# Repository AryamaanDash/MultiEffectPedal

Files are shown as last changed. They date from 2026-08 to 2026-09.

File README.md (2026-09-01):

# MultiEffectPedal

## Description

Multi-effect guitar pedal firmware and a custom KiCad PCB for the Daisy Seed.
The firmware runs distortion, stereo reverb, delay, and flanger effects at the
Daisy audio sample rate, with a footswitch for cycling through the effects.

## Firmware architecture

```text
src/main.cpp             Hardware composition and application entry point
src/AudioEngine.cpp      Real-time block processing and output limiting
src/EffectManager.cpp    Effect ownership-independent routing and mode changes
src/PedalControls.cpp    Foreground switch scanning and LED state
src/effects/             Individual DSP effect adapters
include/                 Public interfaces and shared audio types
```

Every effect implements the `EffectProcessor` interface:

```cpp
virtual void Init(float sample_rate) = 0;
virtual void SetParameters(const EffectParameters& parameters) = 0;
virtual StereoFrame Process(float input) = 0;
```

Effect parameters use normalized values from 0 to 1. Each adapter maps those
values to the range expected by its DaisySP processor. Mode changes are sent
from the foreground loop through an atomic request and applied by the audio
engine at the next block boundary.

The reverb and one-second delay buffers remain in external SDRAM. Effect
objects and the manager are statically allocated; audio processing performs no
dynamic allocation.

## Building

This project expects `libDaisy` and `DaisySP` to be available at the paths in
the `Makefile`.

```sh
make
```

To add an effect, implement `EffectProcessor`, register the instance with
`EffectManager`, and add its source file to `CPP_SOURCES` in the `Makefile`.

## Tools

- Daisy Seed and libDaisy
- DaisySP and DaisySP-LGPL
- KiCad PCB and schematic design

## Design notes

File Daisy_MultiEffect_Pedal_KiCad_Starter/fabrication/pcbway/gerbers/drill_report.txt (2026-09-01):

Drill report for Daisy_MultiEffect_Pedal.kicad_pcb
Created on 2026-08-16T17:45:17

Copper Layer Stackup:
    =============================================================
    L1 :  F.Cu                      front
    L2 :  B.Cu                      back

Drill file 'Daisy_MultiEffect_Pedal.drl' contains
    plated through holes:
    =============================================================
    T1  0.800mm  0.0315"  (36 holes))
    T2  0.900mm  0.0354"  (55 holes))
    T3  1.200mm  0.0472"  (6 holes))

    Total plated holes count 97

Not plated through holes are merged with plated holes
    unplated through holes:
    =============================================================

    Total unplated holes count 0

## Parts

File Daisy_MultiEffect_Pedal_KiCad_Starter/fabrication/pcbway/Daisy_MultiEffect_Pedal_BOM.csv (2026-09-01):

Refs | Value | Footprint | Qty | DNP
C1 | 10uF VREF bulk | Custom:TH_2Pin_7p62 | 1
C2 | 100nF VREF bypass | Custom:TH_2Pin_7p62 | 1
C3 | 100nF op-amp decouple | Custom:TH_2Pin_7p62 | 1
C4 | 1uF input coupling | Custom:TH_2Pin_7p62 | 1
C5 | 1uF into Daisy | Custom:TH_2Pin_7p62 | 1
C6 | 1uF from Daisy Out | Custom:TH_2Pin_7p62 | 1
C7 | 10uF final output coupling | Custom:TH_2Pin_7p62 | 1
J1 | Input TS jack: tip/sleeve | Custom:Jack_or_Switch_2Pin | 1
J2 | Output TS jack: tip/sleeve | Custom:Jack_or_Switch_2Pin | 1
R1 | 100k VREF top | Custom:TH_2Pin_7p62 | 1
R2 | 100k VREF bottom | Custom:TH_2Pin_7p62 | 1
R3 | 1M to VREF | Custom:TH_2Pin_7p62 | 1
R4 | 100R | Custom:TH_2Pin_7p62 | 1
R5 | 100k output bias | Custom:TH_2Pin_7p62 | 1
R6 | 100R output iso | Custom:TH_2Pin_7p62 | 1
R7 | 100k pulldown | Custom:TH_2Pin_7p62 | 1
RV1 | B10K wet/dry | Custom:Pot_3Pin_B10K_Wired | 1
RV2 | B10K amount | Custom:Pot_3Pin_B10K_Wired | 1
RV3 | B10K time/rate | Custom:Pot_3Pin_B10K_Wired | 1
RV4 | B10K feedback | Custom:Pot_3Pin_B10K_Wired | 1
RV5 | B10K output level | Custom:Pot_3Pin_B10K_Wired | 1
SW1 | Momentary mode switch | Custom:Jack_or_Switch_2Pin | 1
U1 | MCP6002 dual op-amp | Package_DIP:DIP-8_W7.62mm | 1
U2 | Daisy Seed minimal pinout | Custom:Daisy_Seed_2x20_Socket | 1

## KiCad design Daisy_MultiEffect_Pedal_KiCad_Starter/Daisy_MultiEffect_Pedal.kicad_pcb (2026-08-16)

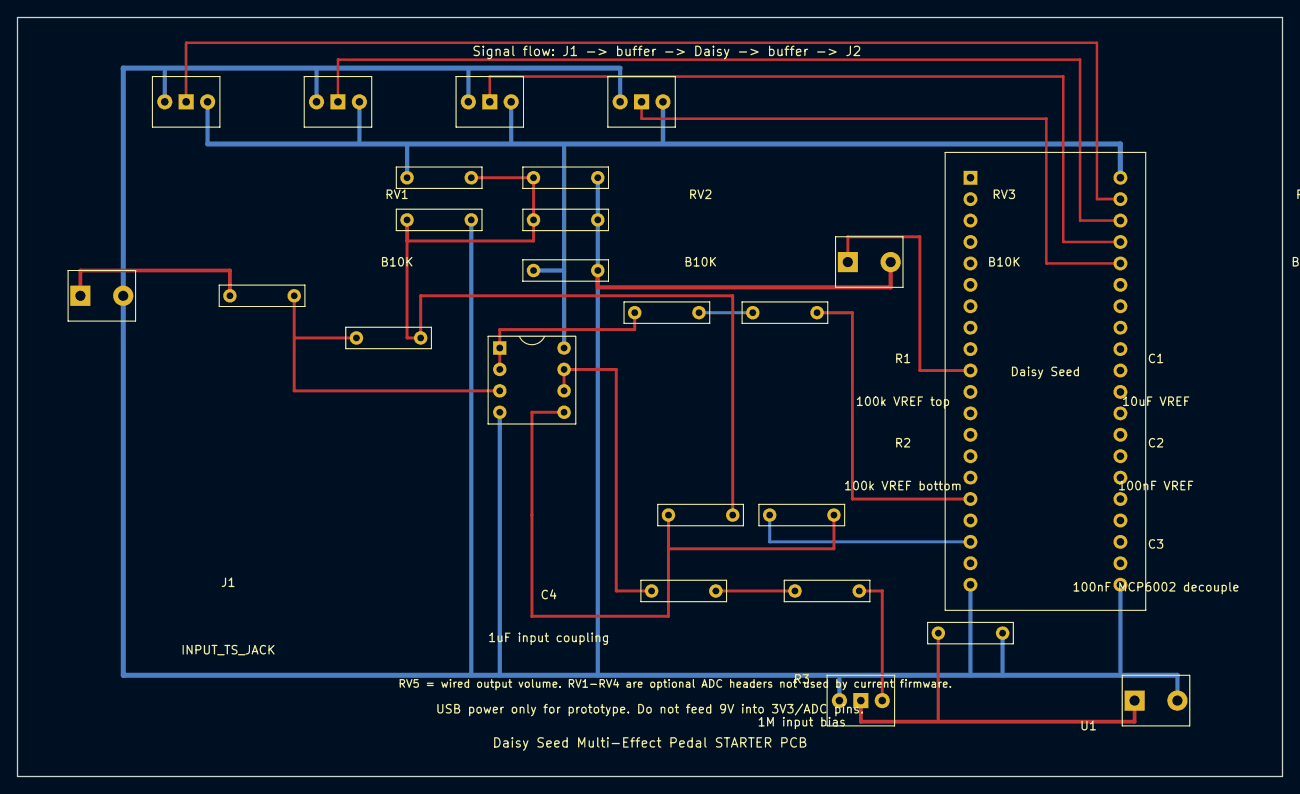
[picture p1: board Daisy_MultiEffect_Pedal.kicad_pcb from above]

Board: 2 copper layers, 150.0 x 90.0 mm, 24 parts (0 on the bottom side), 19 nets.

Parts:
C1: 10uF VREF; TH_2Pin_7p62
C2: 100nF VREF; TH_2Pin_7p62
C3: 100nF MCP6002 decouple; TH_2Pin_7p62
C4: 1uF input coupling; TH_2Pin_7p62
C5: 1uF to Daisy In; TH_2Pin_7p62
C6: 1uF from Daisy Out; TH_2Pin_7p62
C7: 10uF output coupling; TH_2Pin_7p62
J1: INPUT_TS_JACK; Jack_or_Switch_2Pin
J2: OUTPUT_TS_JACK; Jack_or_Switch_2Pin
R1: 100k VREF top; TH_2Pin_7p62
R2: 100k VREF bottom; TH_2Pin_7p62
R3: 1M input bias; TH_2Pin_7p62
R4: 100R; TH_2Pin_7p62
R5: 100k out bias; TH_2Pin_7p62
R6: 100R out iso; TH_2Pin_7p62
R7: 100k output pulldown; TH_2Pin_7p62
RV1, RV2, RV3, RV4: B10K; Pot_3Pin_B10K_Wired
RV5: B10K volume; Pot_3Pin_B10K_Wired
SW1: MOMENTARY_MODE_SWITCH; Jack_or_Switch_2Pin
U1: MCP6002-I/P; DIP-8_W7.62mm
U2: Daisy Seed socket / 2x20; Daisy_Seed_2x20_Socket

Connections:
+3V3A: C3.1, R1.1, RV1.3 (CW/3V3A), RV2.3 (CW/3V3A), RV3.3 (CW/3V3A), RV4.3 (CW/3V3A), U1.8, U2.21 (PIN21)
AUDIO_IN_L: C5.2, U2.16 (PIN16)
AUDIO_OUT_L: C6.1, U2.18 (PIN18)
BUF_IN_OUT: R4.1, U1.1, U1.2
BUF_TO_DAISY_C: C5.1, R4.2
D9_SWITCH: SW1.1 (TIP/SW1), U2.10 (PIN10)
GND: C1.2, C2.2, C3.2, J1.2 (SLEEVE/SW2), J2.2 (SLEEVE/SW2), R2.2, R7.2, RV1.1 (CCW/GND), RV2.1 (CCW/GND), RV3.1 (CCW/GND), RV4.1 (CCW/GND), RV5.1 (CCW/GND), SW1.2 (SLEEVE/SW2), U1.4, U2.20 (PIN20), U2.40 (PIN40)
INPUT_NODE: C4.2, R3.1, U1.3
IN_JACK_TIP: C4.1, J1.1 (TIP/SW1)
OUT_BUF_INPUT: C6.2, R5.1, U1.5
OUT_BUF_OUT: R6.1, U1.6, U1.7
OUT_CAP_IN: C7.1, R6.2
OUT_JACK_TIP: J2.1 (TIP/SW1), R7.1, RV5.2 (WIPER)
OUT_LEVEL_IN: C7.2, RV5.3 (CW/LEVEL_IN)
POT1_A0_D15: RV1.2 (WIPER), U2.22 (PIN22)
POT2_A1_D16: RV2.2 (WIPER), U2.23 (PIN23)
POT3_A2_D17: RV3.2 (WIPER), U2.24 (PIN24)
POT4_A3_D18: RV4.2 (WIPER), U2.25 (PIN25)
VREF_1V65: C1.1, C2.1, R1.2, R2.1, R3.2, R5.2

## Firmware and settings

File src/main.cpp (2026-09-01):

#include "daisy_seed.h"
#include "daisysp-lgpl.h"

#include "AudioEngine.h"
#include "EffectManager.h"
#include "PedalControls.h"
#include "effects/BypassEffect.h"
#include "effects/DelayEffect.h"
#include "effects/DistortionEffect.h"
#include "effects/FlangerEffect.h"
#include "effects/ReverbEffect.h"

namespace
{
daisy::DaisySeed hardware;

// These two processors contain large internal buffers and must remain in the
// Daisy Seed's external SDRAM.
daisysp::ReverbSc DSY_SDRAM_BSS  reverb_processor;
pedal::DelayBuffer DSY_SDRAM_BSS delay_buffer;

pedal::BypassEffect     bypass_effect;
pedal::DistortionEffect distortion_effect;
pedal::ReverbEffect     reverb_effect(reverb_processor);
pedal::DelayEffect      delay_effect(delay_buffer);
pedal::FlangerEffect    flanger_effect;

pedal::EffectManager effect_manager(bypass_effect,
                                    distortion_effect,
                                    reverb_effect,
                                    delay_effect,
                                    flanger_effect);
pedal::AudioEngine   audio_engine(effect_manager);
pedal::PedalControls controls(hardware, effect_manager);

void AudioCallback(daisy::AudioHandle::InputBuffer  input,
                   daisy::AudioHandle::OutputBuffer output,
                   size_t                           size)
{
    audio_engine.ProcessBlock(input, output, size);
}
} // namespace

int main(void)
{
    hardware.Init();
    hardware.SetAudioBlockSize(4);

    audio_engine.Init(hardware.AudioSampleRate());
    controls.Init();

    hardware.StartAudio(AudioCallback);

    while(true)
    {
        controls.Process();
        daisy::System::Delay(1);
    }
}

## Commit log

2026-07-15 added pcb + schematic design
    [Daisy_MultiEffect_Pedal.kicad_pcb, Daisy_MultiEffect_Pedal.kicad_sch]
2026-07-19 made fixes to schematic and pcb design, added readme
    [Daisy_MultiEffect_Pedal.kicad_pcb, Daisy_MultiEffect_Pedal.kicad_sch]
2026-08-16 fixed PCB and schematic files, finalized PCB design for ordering
    [Daisy_MultiEffect_Pedal.kicad_pcb, Daisy_MultiEffect_Pedal.kicad_sch]
2026-09-01 updated PCB design
    [Daisy_MultiEffect_Pedal-B_Cu.gbl, Daisy_MultiEffect_Pedal-B_Mask.gbs, Daisy_MultiEffect_Pedal-B_Silkscreen.gbo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]
